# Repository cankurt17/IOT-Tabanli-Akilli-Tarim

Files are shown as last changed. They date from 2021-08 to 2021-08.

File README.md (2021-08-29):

# IOT-Tabanli-Akilli-Tarim

- Bu proje tarımda sulama ve gübrelemedeki insan yüklerini azaltmak için geliştirilmiştir. Otomatik gübreleme ve 2 farklı sulama modu seçeneği ile maksimum verimde gübreleme ve sulama yapabilmektedir. Kullanıcı dostu arayüzü ve hatasız çalışma sistemi ile çiftçilerin şüphesiz tercih edeceği bir proje olması hedeflenmektedir. 
- Sistemin çalışma mantığı kullanıcı panodan veya mobil uygulamadan sulama yapacağı saat aralığını sisteme girer. Örneğin pazartesi saat 20.00 - 21.30 aralığında sisteme sulama girilmiş ise sistem belirtilen saat aralığında bahçenin suyunu açar ve kullanıcıya bilgilendirme maili gönderir. Eğer kullanıcı gübre miktarını girerek gübreleme yapılacağını sisteme belirtmiş ise sistem suyun debisini hesaplayarak girilen  miktardaki gübreyi suya aktarır ve gübrelemeyi tamamlar.
  Bütün bu sistemin çalışması sırasında bir arıza olursa kullanıcı mail ile bilgilendirilir. Örneğin su kesintisi,gübrenin bitmesi, elektrik kesintisi vb. Sulama sırasında sorun yaşanmaz ise kullanıcı bilgilendirilerek sulama kaydı tutulur ve tabloya aktarılır.
- Otomatik modda kullanıcının girdiği nem değerleri baz alınarak sistem   saatten bağımsız olarak toprağı istenilen nem aralığında tutar.Manuel modda ise kullanıcının girdiği saat aralıklarında sulama yapmaktadır. 

# Proje Özellikleri

- Otomatik ve manuel olmak üzere 2 farklı modda sulama seçeneği
- Mobil uygulama destekli
- Kullanıcı dostu kontrol panosu
- Otomatik sulama 
- Otomatik gübreleme 
- Bahçe toprağının anlık nem takibi
- Havanın sıcaklık ve nem takibi
- Gübrenin miktarı takibi
- Suyun durum ve debi takibi
- Bildirim ve mail ile bilgilendirme servisi
- Su sayacı 
- Ayrıntılı sulama kayıt tablosu
- Arıza rapor servisi 

# Prototip Görselleri
prototip1
prototoip2

# Mobil uygulama görselleri

uygulama1
uygulama2
uygulama3
uygulama4
uygulama5
uygulama6

# Pano görselleri

pano1
pano2
pano3
pano4

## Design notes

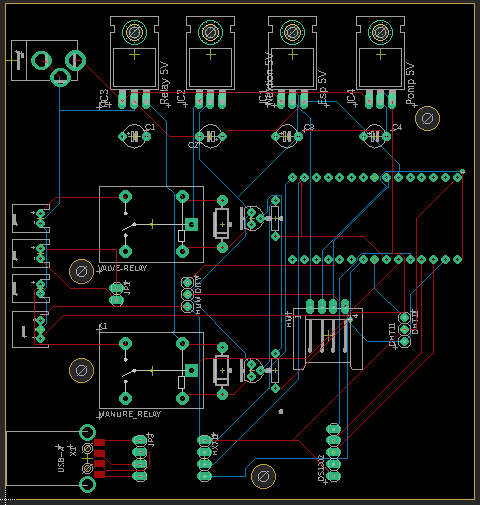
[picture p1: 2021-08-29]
Eagle/board.png

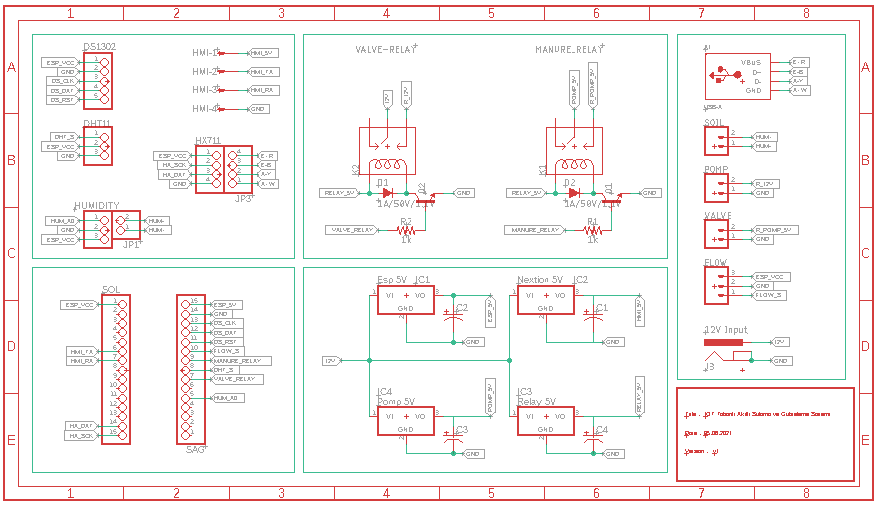
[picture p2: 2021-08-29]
Eagle/schema.png

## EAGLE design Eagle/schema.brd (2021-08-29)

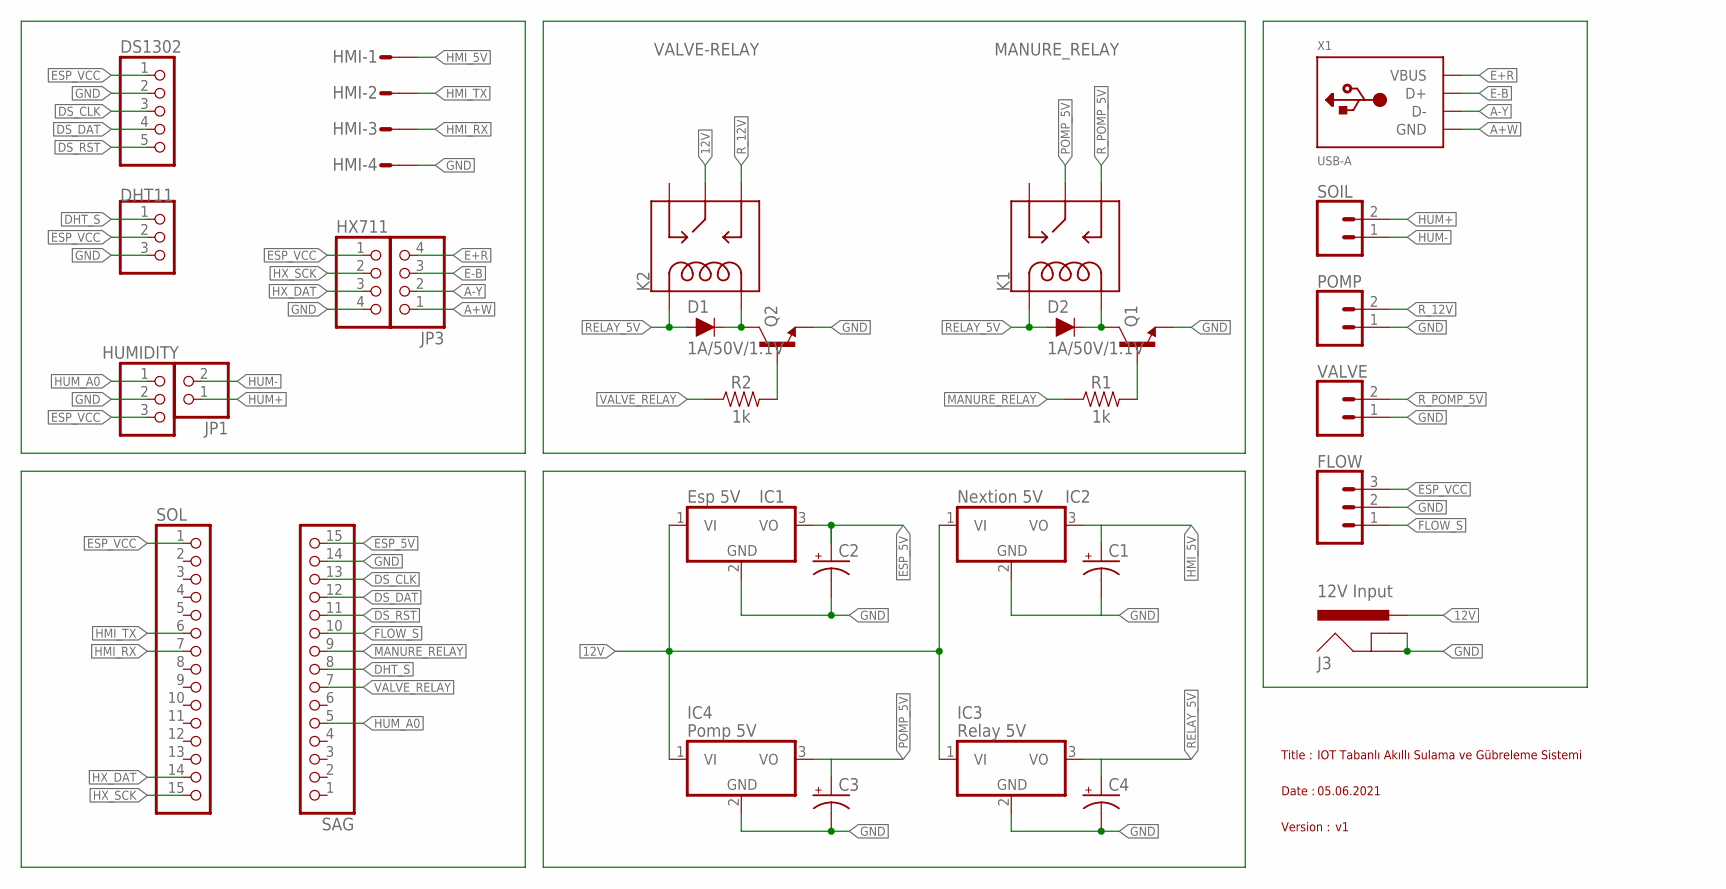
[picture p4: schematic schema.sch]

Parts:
C1, C2, C3, C4: CPOL-USE5-5; E5-5
D1, D2: 1A/50V/1.1V; DIODE-1N4001
DHT11: DHT11; 1X03
DS1302: PINHD-1X5; 1X05
FLOW: CONN_03JST-PTH; JST-3-PTH
HMI: L04P
HUMIDITY: PINHD-1X3; 1X03
HX711: PINHD-1X4; 1X04
IC1: Esp 5V; TO220H
IC2: Nextion 5V; TO220H
IC3: Relay 5V; TO220H
IC4: Pomp 5V; TO220H
J3: 12V Input; POWER_JACK_PTH_LOCK
JP1: PINHD-1X2; 1X02
JP3: PINHD-1X4; 1X04
K1: MANURE_RELAY; RELAY_G5LE
K2: VALVE-RELAY; RELAY_G5LE
POMP: CONN_02-JST-2-PTH-NO_SILK; JST-2-PTH-NS
Q1, Q2: 200mA/40V; TO-92
R1, R2: 1k; AXIAL-0.3
SAG: PINHD-1X15-CB; 1X15-CB
SOIL: CONN_02-JST-2-PTH-NO_SILK; JST-2-PTH-NS
SOL: PINHD-1X15-CB; 1X15-CB
VALVE: CONN_02-JST-2-PTH-NO_SILK; JST-2-PTH-NS
X1: USB-A; MOLEX_480371000

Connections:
12V: IC1.1 (VI), IC2.1 (VI), IC3.1 (VI), IC4.1 (VI), J3.PWR, K2.1 (MAIN)
A+W: JP3.1, X1.4 (GND)
A-Y: JP3.2, X1.2 (D-)
DHT_S: DHT11.1, SAG.8
DS_CLK: DS1302.3, SAG.13
DS_DAT: DS1302.4, SAG.12
DS_RST: DS1302.5, SAG.11
E+R: JP3.4, X1.1 (VBUS)
E-B: JP3.3, X1.3 (D+)
ESP_5V: C2.+, IC1.3 (VO), SAG.15
ESP_5V1: C1.+
ESP_5V2: C4.+
ESP_5V3: C3.+
ESP_VCC: DHT11.2, DS1302.1, FLOW.3, HUMIDITY.3, HX711.1, SOL.1
FLOW_S: FLOW.1, SAG.10
GND: C2.-, C3.-, C4.-, DHT11.3, DS1302.2, FLOW.2, HMI.4, HUMIDITY.2, HX711.4, IC1.2 (GND), IC2.2 (GND), IC3.2 (GND), IC4.2 (GND), J3.GND, J3.GNDBREAK, POMP.1, Q1.1 (E), Q2.1 (E), SAG.14, VALVE.1
GND2: C1.-
HMI_5V: HMI.1, IC2.3 (VO)
HMI_RX: HMI.3, SOL.7
HMI_TX: HMI.2, SOL.6
HUM+: JP1.1, SOIL.2
HUM-: JP1.2, SOIL.1
HUM_A0: HUMIDITY.1, SAG.5
HX_DAT: HX711.3, SOL.14
HX_SCK: HX711.2, SOL.15
MANURE_RELAY: R1.P$1 (1), SAG.9
unnamed: D2.C, K1.5 (COIL2), Q1.3 (C)
unnamed: Q1.2 (B), R1.P$2 (2)
unnamed: D1.C, K2.5 (COIL2), Q2.3 (C)
unnamed: Q2.2 (B), R2.P$2 (2)
POMP_5V: IC4.3 (VO), K1.1 (MAIN)
RELAY_5V: D1.A, D2.A, IC3.3 (VO), K1.2 (COIL1), K2.2 (COIL1)
R_12V: K2.3 (NO), POMP.2
R_POMP_5V: K1.3 (NO), VALVE.2
VALVE_RELAY: R2.P$1 (1), SAG.7

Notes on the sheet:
Title :
IOT Tabanlı Akıllı Sulama ve Gübreleme Sistemi
Date :
05.06.2021
Version :

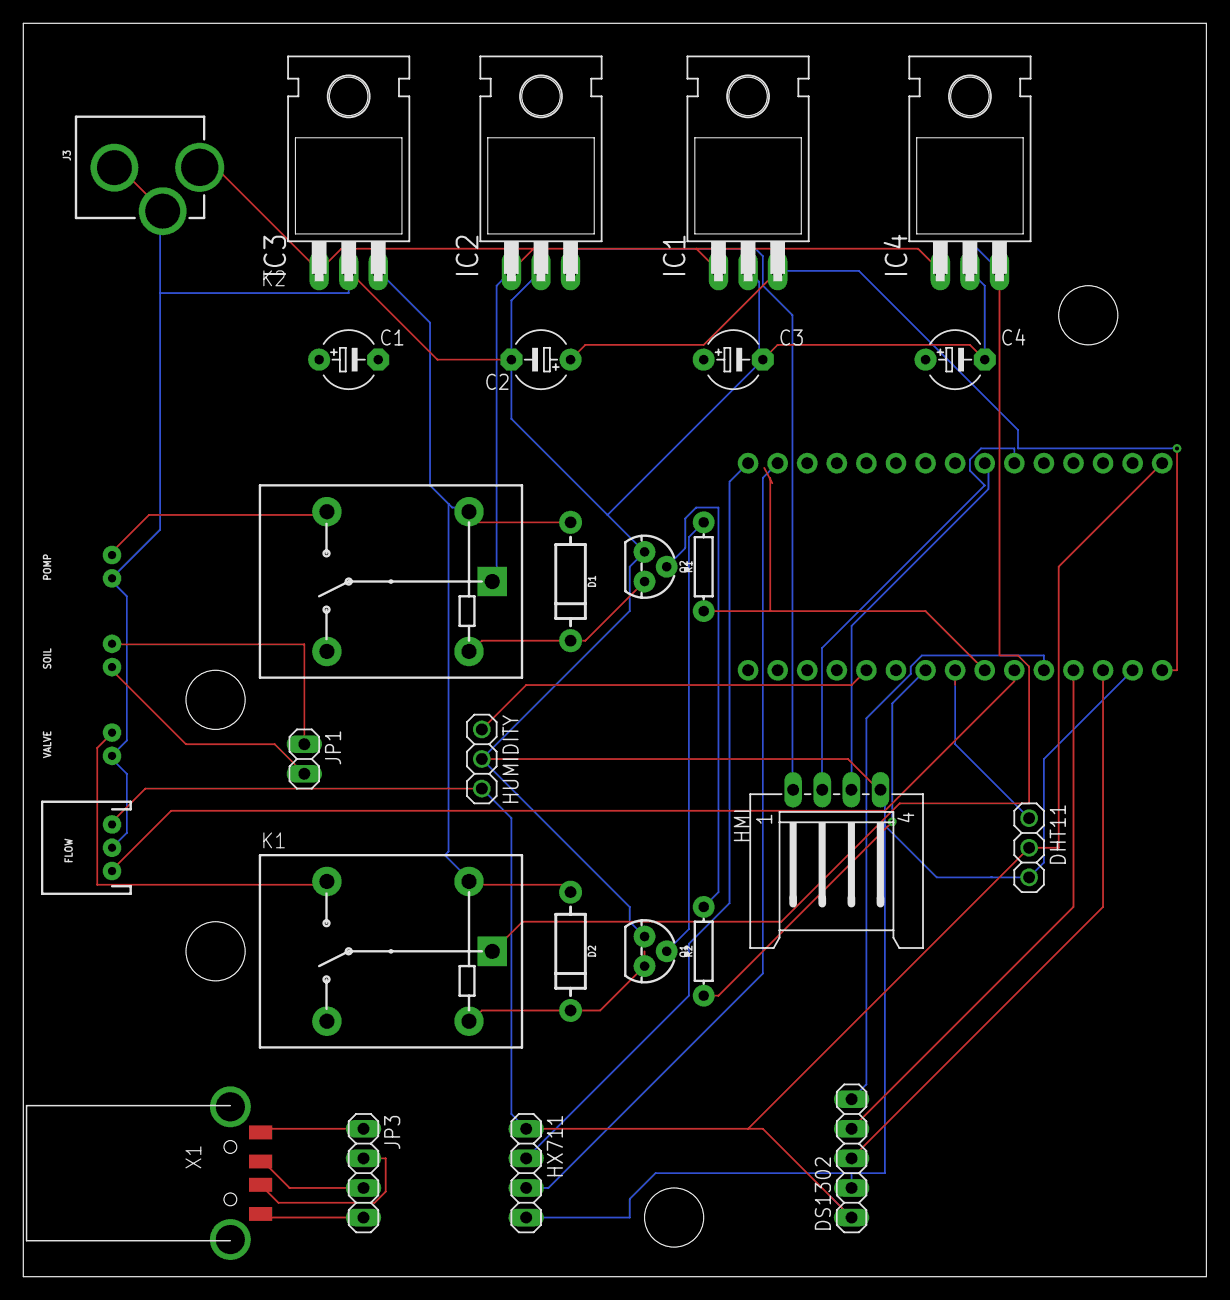
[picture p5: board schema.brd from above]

Board: 2 copper layers, 101.6 x 107.6 mm, 31 parts (0 on the bottom side), 31 nets.

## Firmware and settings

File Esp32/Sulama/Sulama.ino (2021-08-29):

#include "EasyNextionLibrary.h"
#include <EEPROM.h>
#include <virtuabotixRTC.h>
#include <DHT.h>
#include <WiFi.h>
#include <HTTPClient.h>
#include <Arduino_JSON.h>
#include "HX711.h"


EasyNex myNex(Serial2);
#define DHTTYPE DHT11

String id_sulama_durum[7] = {"manuel_ekran.cPt", "manuel_ekran.cSl", "manuel_ekran.cCrs", "manuel_ekran.cPrs", "manuel_ekran.cCm", "manuel_ekran.cCt", "manuel_ekran.cPz",};
String id_sulama_baslaSaat[7] = {"manuel_ekran.ptBasla", "manuel_ekran.slBasla", "manuel_ekran.crsBasla", "manuel_ekran.prsBasla", "manuel_ekran.cmBasla", "manuel_ekran.ctBasla", "manuel_ekran.pzBasla",};
String id_sulama_bitisSaat[7] = {"manuel_ekran.ptBitir", "manuel_ekran.slBitir", "manuel_ekran.crsBitir", "manuel_ekran.prsBitir", "manuel_ekran.cmBitir", "manuel_ekran.ctBitir", "manuel_ekran.pzBitir",};

String id_gubre_durum[7] = {"gubre_ayar.g_cPt", "gubre_ayar.g_cSl", "gubre_ayar.g_cCrs", "gubre_ayar.g_cPrs", "gubre_ayar.g_cCm", "gubre_ayar.g_cCt", "gubre_ayar.g_cPz",};
String id_gubre_miktar[7] = {"gubre_ayar.ptMiktar", "gubre_ayar.slMiktar", "gubre_ayar.crsMiktar", "gubre_ayar.prsMiktar", "gubre_ayar.cmMiktar", "gubre_ayar.ctMiktar", "gubre_ayar.pzMiktar",};
String id_gubre_birim[7] = {"gubre_ayar.ptBirim", "gubre_ayar.slBirim", "gubre_ayar.crsBirim", "gubre_ayar.prsBirim", "gubre_ayar.cmBirim", "gubre_ayar.ctBirim", "gubre_ayar.pzBirim",};

String id_sulama_nem[2] = {"manuel_nem.nemBasla", "manuel_nem.nemBitir"};
String id_sulama_mod = {"mod_ekran.mod" };
String id_dekar = {"dekar_ekran.dekar" };
String id_suSayaci = {"su_sayaci.suSayaci" };

String gunler[7] = {"Pazartesi", "Salı", "Çarşamba", "Perşembe", "Cuma", "Cumartesi", "Pazar"};

const char* mailServer = "http://maker.ifttt.com/trigger/esp_mail/with/key/dOcBsvl9Rl1Jaqve76vQB2";

const char* writeServer = "https://enlodi.com/Sulama-Proje/post-esp-data.php";
const char* readServer = "https://enlodi.com/Sulama-Proje/";
String apiKeyValue = "tPmAT5Ab3j7F9";
String httpRequestData;
//const char* ssid     = "KURT";
//const char* password = "enlodi.46";
const char* ssid     = "G4_7465";
const char* password = "11111111";

String mailAdresi;

unsigned long eskizaman = 0;
int sulama_durum[7];
String sulama_baslaSaat[7];
String sulama_bitisSaat[7];
int gubre_durum[7];
int gubre_miktar[7];
String gubre_birim[7];
int sulama_nem[2];
int sulama_mod;
int dekar;
int suSayaci;
int toplamSulama;
bool suKesintisi = false;
int kesintiSayisi = 0;
unsigned long kesintiZaman = 0;
String gubreBirimler[2] = {"mL", "L"};

uint32_t ekranKayit = 0 ;
String text = "";
uint32_t asd = 0 ;

byte lsb;
byte msb;
unsigned long ekran_zaman = 0;
String suDurum = "KAPALI";
String gubreDurum = "KAPALI";

///////////////////////////////// Pinler
int suVana = 33;
int gubreVana = 26;
int Saat_CLK_PIN = 13 ;
int Saat_DT_PIN = 12;
int Saat_RST_PIN = 14 ;
const int DHTPin = 25;
int nem_sensor = 35;
const int debi_sensor = 27;
#define DOUT 22
#define CLK 23


HX711 scale(DOUT, CLK);
float kalibrasyon_faktoru = 103000;

bool debiKontrol;
int hata = 1;

int debi = 0;
int nemdeger = 0;
String sulamaRapor;
int ortDebi = 0;
int _gun;

int debiSaniye = 120000;
int gubreSaniye = 300000;
int veriMod;
int veriGubre;
String veriBaslamaSaati;
String veriBitisSaati;
int veriBaslamaNem;
int veriBitisNem;
int veriAnlikNem;
unsigned long veriSuBaslama = 0;
unsigned long mysql_zaman = 0;
float veriAtilacakGubre = 0;
float veriAnlikGubre = 0;
float gubreMiktar = 0;

volatile int  Pulse_Count;
unsigned int  Liter_per_hour;
unsigned long Current_Time, Loop_Time;

DHT dht(DHTPin, DHTTYPE);
virtuabotixRTC myRTC(Saat_CLK_PIN, Saat_DT_PIN, Saat_RST_PIN);

void setup() {
  myNex.begin(115200); // Begin the object with a baud rate of 9600
  Serial.begin(115200);                  // If no parameter was given in the begin(), the default baud rate of 9600 will be used v
  EEPROM.begin(512);
  dht.begin();
  pinMode(nem_sensor, INPUT);
  pinMode(suVana, OUTPUT);
  pinMode(gubreVana, OUTPUT);
  pinMode(debi_sensor, INPUT);
  digitalWrite(suVana, LOW);
  scale.set_scale(kalibrasyon_faktoru); // Ölçek ayarlandı
  scale.tare(); // Ölçek sıfırlandı
  attachInterrupt(digitalPinToInterrupt(debi_sensor), Detect_Rising_Edge, RISING);
  Current_Time = millis();
  Loop_Time = Current_Time;
  loadEEPROM();
  loadNextion();
  initWiFi();
}


void loop() {
  myNex.NextionListen();
  myRTC.updateTime();
  homePage();
  ekranKayit = myNex.readNumber ( "settings.kayitEkran.val" );
  Current_Time = millis();
  getDebiSensor();
  sulamaKontrol();
  mysqlKontrol();
  debiHesapla();
  suKontrol();
  wifiKontrol();
  if (ekranKayit == 1) {

    getNextionMod();
    writeModEEPROM();
    mysqlModKayit();
  }
  if (ekranKayit == 2) {
    getNextionSulama();
    writeSulamaEEPROM();
    mysqlGunKayit();
  }
  if (ekranKayit == 3) {
    getNextionNem();
    writeNemEEPROM();
    mysqlNemKayit();
  }
  if (ekranKayit == 4) {
    getNextionGubre();
    writeGubreEEPROM();
    mysqlGubreKayit();
  }
  if (ekranKayit == 5) {
    getNextionDekar();
    writeDekarEEPROM();
    kayitEkran();
  }
  if (ekranKayit == 6) {
    writeSayacEEPROM(0);
    kayitEkran();
  }
  if (ekranKayit == 7) {
    saatKayit();
    kayitEkran();
  }
}

//////////////////////////////////////////////////////////////////////////////////////////////////////  getNextion
void getNextionSulama() {
  for (int i = 0; i <= 6; i++) {
    sulama_durum[i] = myNex.readNumber( id_sulama_durum[i] + ".val" );
    sulama_baslaSaat[i] = myNex.readStr( id_sulama_baslaSaat[i] + ".txt" );
    sulama_bitisSaat[i] = myNex.readStr( id_sulama_bitisSaat[i] + ".txt" );
  }
  for (int i = 0; i <= 6; i++) {
    Serial.println(sulama_durum[i]);
    Serial.println(sulama_baslaSaat[i]);
    Serial.println(sulama_bitisSaat[i]);
  }
}
void getNextionNem() {
  sulama_nem[0] = myNex.readNumber( id_sulama_nem[0] + ".val"  );
  sulama_nem[1] = myNex.readNumber( id_sulama_nem[1] + ".val"  );
}
void getNextionMod() {
  sulama_mod = myNex.readNumber( id_sulama_mod + ".val"  );
  String abc = myNex.readStr( "mod_ekran.b2.txt" );
  Serial.println(sulama_mod);
  Serial.println(abc);
}
void getNextionGubre() {
  for (int i = 0; i <= 6; i++) {
    gubre_durum[i] = myNex.readNumber( id_gubre_durum[i] + ".val" );
    gubre_miktar[i] = myNex.readStr( id_gubre_miktar[i] + ".txt" ).toInt();
    gubre_birim[i] = myNex.readStr( id_gubre_birim[i] + ".txt" );
  }
  for (int i = 0; i <= 6; i++) {
    Serial.println(gubre_durum[i]);
    Serial.println(gubre_miktar[i]);
    Serial.println(gubre_birim[i]);
  }
}

void getNextionDekar() {
  dekar = myNex.readNumber( id_dekar + ".val"  );
}
//////////////////////////////////////////////////////////////////////////////////////////////////////  setNextion
void setNextionSulama() {
  for (int i = 0; i <= 6; i++) {
    myNex.writeNum( id_sulama_durum[i] + ".val", sulama_durum[i] );
    myNex.writeStr( id_sulama_baslaSaat[i] + ".txt", sulama_baslaSaat[i] );
    myNex.writeStr( id_sulama_bitisSaat[i] + ".txt", sulama_bitisSaat[i]);
  }
}
void setNextionNem() {
  myNex.writeNum( id_sulama_nem[0] + ".val", sulama_nem[0]);
  myNex.writeNum( id_sulama_nem[1] + ".val", sulama_nem[1]);
}
void setNextionMod() {
  myNex.writeNum( id_sulama_mod + ".val", sulama_mod);
}
void setNextionGubre() {
  for (int i = 0; i <= 6; i++) {
    myNex.writeNum( id_gubre_durum[i] + ".val" , gubre_durum[i]);
    myNex.writeStr( id_gubre_miktar[i] + ".txt", String(gubre_miktar[i]) );
    myNex.writeStr( id_gubre_birim[i] + ".txt" , gubre_birim[i]);
  }
}
void setNextionDekar() {
  myNex.writeNum( id_dekar + ".val", dekar);
}
void setNextionSayac() {
  myNex.writeNum( id_suSayaci + ".val", suSayaci);
}
//////////////////////////////////////////////////////////////////////////////////////////////////////  writeEEPROM
void writeSulamaEEPROM() {
  int addr = 1;
  for (int i = 0; i <= 6; i++) {
    writeEEPROM(addr, sulama_durum[i]);
    writeEEPROM(addr + 1, sulama_baslaSaat[i].substring(0, 2).toInt());
    writeEEPROM(addr + 2, sulama_baslaSaat[i].substring(3, 5).toInt());
    writeEEPROM(addr + 3, sulama_bitisSaat[i].substring(0, 2).toInt());
    writeEEPROM(addr + 4, sulama_bitisSaat[i].substring(3, 5).toInt());
    addr = addr + 5;
  }

}
void writeNemEEPROM() {
  writeEEPROM(40, sulama_nem[0]);
  writeEEPROM(41, sulama_nem[1]);
}
void writeModEEPROM() {
  writeEEPROM(42, sulama_mod);
}
void writeGubreEEPROM() {
  int addr = 45;
  for (int i = 0; i <= 6; i++) {
    intToByte(gubre_miktar[i]);
    writeEEPROM(addr, gubre_durum[i]);
    writeEEPROM(addr + 1, lsb);
    writeEEPROM(addr + 2, msb);
    writeEEPROM(addr + 3, getGubreBirim(gubre_birim[i]));
    addr = addr + 4;
  }
}
void writeDekarEEPROM() {
  intToByte(dekar);
  writeEEPROM(90, lsb);
  writeEEPROM(91, msb);
}
void writeSayacEEPROM(int sayac) {
  intToByte(sayac);
  writeEEPROM(92, lsb);
  writeEEPROM(93, msb);
}
//////////////////////////////////////////////////////////////////////////////////////////////////////  readEEPROM
void readSulamaEEPROM() {
  EEPROM.begin(512);
  int addr = 1;
  for (int i = 0; i <= 6; i++) {
    sulama_durum[i] = EEPROM.read(addr);
    sulama_baslaSaat[i] = setClockText(EEPROM.read(addr + 1), EEPROM.read(addr + 2));
    sulama_bitisSaat[i] = setClockText(EEPROM.read(addr + 3), EEPROM.read(addr + 4));
    addr = addr + 5;
  }
}

void readNemEEPROM() {
  sulama_nem[0] = EEPROM.read(40);
  sulama_nem[1] = EEPROM.read(41);
}
void readModEEPROM() {
  EEPROM.begin(512);
  sulama_mod = EEPROM.read(42);
}

void readGubreEEPROM() {
  int addr = 45;
  for (int i = 0; i <= 6; i++) {
    gubre_durum[i] =  EEPROM.read(addr);
    gubre_miktar[i] =  byteToInt(EEPROM.read(addr + 1), EEPROM.read(addr + 2));
    gubre_birim[i] =  gubreBirimler[EEPROM.read(addr + 3)] ;
    addr = addr + 4;
  }
}

void readDekarEEPROM() {
  EEPROM.begin(512);
  dekar = byteToInt(EEPROM.read(90), EEPROM.read(91));
}

void readSayacEEPROM() {
  EEPROM.begin(512);
  suSayaci = byteToInt(EEPROM.read(92), EEPROM.read(93));
}
//////////////////////////////////////////////////////////////////////////////////////////////////////  startApp

void loadEEPROM() {
  readSulamaEEPROM();
  readNemEEPROM();
  readModEEPROM();
  readGubreEEPROM();
  readDekarEEPROM();
  readSayacEEPROM();
}
void loadNextion() {
  setNextionSulama();
  setNextionNem();
  setNextionMod();
  setNextionGubre();
  setNextionDekar();
  setNextionSayac();
}
/////////////////////////////////////////////////////////////////////////////////////////////////////


void writeEEPROM(int addr, int value) {
  if (EEPROM.read(addr) != value) {
    EEPROM.begin(512);
    EEPROM.write(addr, value);
    EEPROM.commit();
  }
}

void intToByte(int value) {
  lsb = lowByte(value);
  msb = highByte(value);
}

int byteToInt(byte a, byte b) {
  return a + (b << 8);
}

int getGubreBirim(String birim) {
  int _birim;
  if (birim == "mL") {
    _birim = 0;
  } else if (birim == "L") {
    _birim = 1;
  }
  return _birim;
}

String setClockText(int saat, int dk) {
  String deger;
  if (saat < 10) {
    if (dk < 10) {
      deger = "0" + String(saat) + ":" + "0" + String(dk);
    } else {
      deger = "0" + String(saat) + ":" + String(dk);
    }
  } else if (dk < 10) {
    deger = String(saat) + ":" + "0" + String(dk);
  } else {
    deger = String(saat) + ":" + String(dk);
  }
  return deger;
}

void kayitEkran() {
  myNex.writeNum( "p1.pic", 23 );
  myNex.writeStr ("t2.txt", "Bağlantı başarılı.");
  myNex.writeStr( "vis p1,1");
  myNex.writeStr( "vis t2,1");
  delay(100);
  myNex.writeNum( "t0.pco", 1024 );
  myNex.writeStr ("t0.txt", "Kaydedildi.");
  delay(500);
  myNex.writeNum( "settings.kayitEkran.val", 0 );
  myNex.writeStr ("page settings");
  delay(100);
}


void homePage() {
  if (millis() - ekran_zaman > 2000) {
    nemdeger = analogRead(nem_sensor);
    nemdeger = map(nemdeger, 0, 4095, 100, 0);
    gubreMiktar = getTarti();
    if (digitalRead(suVana) == HIGH) {
      suDurum = "AÇIK";
    } else {
      suDurum = "KAPALI";
    }
    if (digitalRead(gubreVana) == HIGH) {
      gubreDurum = "AÇIK";
    } else {
      gubreDurum = "KAPALI";
    }
    myNex.writeNum( "home.saat.val", myRTC.hours);
    myNex.writeNum( "home.dk.val", myRTC.minutes);
    myNex.writeStr( "home.day.txt", gunler[myRTC.dayofweek - 1]);
    myNex.writeStr( "home.sic.txt", String((int)dht.readTemperature()) + "°C");
    myNex.writeStr( "home.nem.txt", "%" + String((int)dht.readHumidity()));
    myNex.writeStr( "home.tnem.txt", "%" + String(nemdeger));
    myNex.writeStr( "home.debi.txt", String(debi) + " L/sa");
    myNex.writeStr( "home.rapor.txt", suRapor());
    myNex.writeStr( "home.suDurum.txt", suDurum);
    myNex.writeStr( "home.gMiktar.txt", String(gubreMiktar, 1) + " Litre");
    myNex.writeStr( "home.gubreDurum.txt", gubreDurum);
    loadNextion();
    ekran_zaman = millis();
  }
}

void saatKayit() {
  int gun = getDay(myNex.readStr("saat_ayar.t0.txt" ));
  int saat = myNex.readNumber("saat_ayar.n0.val" );
  int dk = myNex.readNumber("saat_ayar.n1.val" );
  myRTC.setDS1302Time(00, dk, saat, gun, 10, 1, 2020);
}

int getDay(String gun) {
  int _gun;
  if (gun == "Pazartesi") {
    _gun = 1;
  } else if (gun == "Salı") {
    _gun = 2;
  } else if (gun == "Çarşamba") {
    _gun = 3;
  } else if (gun == "Perşembe") {
    _gun = 4;
  } else if (gun == "Cuma") {
    _gun = 5;
  } else if (gun == "Cumartesi") {
    _gun = 6;
  } else if (gun == "Pazar") {
    _gun = 7;
  }
  return _gun;
}


void getDebiSensor() {
  Current_Time = millis();
  if (Current_Time >= (Loop_Time + 1000))
  {
    Loop_Time = Current_Time;
    Liter_per_hour = (Pulse_Count * 60 / 7.5);
    Pulse_Count = 0;
    debi = Liter_per_hour;
  }
}


void Detect_Rising_Edge ()
{
  Pulse_Count++;
}

String suRapor() {
  int _gun = myRTC.dayofweek - 1;
  if (digitalRead(suVana) == LOW) {

    int saat = myRTC.hours * 100 + myRTC.minutes;
    int basla  = vanaSaatKontrol(sulama_baslaSaat[_gun]);
    if (sulama_durum[_gun] == 1 && saat <= basla) {
      if (gubre_durum[_gun] == 1) {
        return sulamaRapor = "Sıradaki sulama " + gunler[_gun] + " " + sulama_baslaSaat[_gun] + " / " + sulama_bitisSaat[_gun] + "  Gübreleme VAR";
      } else {
        return sulamaRapor = "Sıradaki sulama " + gunler[_gun] + " " + sulama_baslaSaat[_gun] + " / " + sulama_bitisSaat[_gun] + "  Gübreleme YOK";
      }
    }
    for (int i = _gun + 1; i <= 6; i++) {
      int saat = myRTC.hours * 100 + myRTC.minutes;
      int basla  = vanaSaatKontrol(sulama_baslaSaat[i]);

      if (sulama_durum[i] == 1) {
        if (gubre_durum[i] == 1) {
          return sulamaRapor = "Sıradaki sulama " + gunler[i] + " " + sulama_baslaSaat[i] + " / " + sulama_bitisSaat[i] + "  Gübreleme VAR";
        } else {
          return sulamaRapor = "Sıradaki sulama " + gunler[i] + " " + sulama_baslaSaat[i] + " / " + sulama_bitisSaat[i] + "  Gübreleme YOK";
        }
      }

    }
    for (int i = 0; i <= 6; i++) {
      int saat = myRTC.hours * 100 + myRTC.minutes;
      int basla  = vanaSaatKontrol(sulama_baslaSaat[i]);

      if (sulama_durum[i] == 1) {
        if (gubre_durum[i] == 1) {
          return sulamaRapor = "Sıradaki sulama " + gunler[i] + " " + sulama_baslaSaat[i] + " / " + sulama_bitisSaat[i] + "  Gübreleme VAR";
        } else {
          return sulamaRapor = "Sıradaki sulama " + gunler[i] + " " + sulama_baslaSaat[i] + " / " + sulama_bitisSaat[i] + "  Gübreleme YOK";
        }
      }
    }
    return sulamaRapor = "Kayıtlı sulama yok";
  } else {
    if (gubre_durum[_gun] == 1) {
      return sulamaRapor = "Bahçe şuanda sulanıyor Gübreleme VAR";
    } else {
      return sulamaRapor = "Bahçe şuanda sulanıyor Gübreleme YOK";
    }
  }
}
void sulamaKontrol() {
  if (sulama_mod == 1) {
    manSulama();
  }
  else if (sulama_mod == 0) {
    otoSulama();
  }
}
void manSulama() {
  int _gun = myRTC.dayofweek - 1;
  if (sulama_durum[_gun] == 1 ) {
    int basla  = vanaSaatKontrol(sulama_baslaSaat[_gun]);
    int bitir  = vanaSaatKontrol(sulama_bitisSaat[_gun]);
    int saat = myRTC.hours * 100 + myRTC.minutes;
    if (basla <= saat && saat <= bitir) {
      if (digitalRead(suVana) == LOW) {
        digitalWrite(suVana, HIGH);
        Serial.println("1");
        suDurum = "AÇIK";
        debiKontrol = true;
        ortDebi = 0;
        suKesintisi = false;
        veriSuBaslama = millis();
        manSulamaMail();
        sulamaKayitVerileri();
      } else {
        gubreKontrol();
      }
    } else if (digitalRead(suVana) == HIGH) {
      digitalWrite(suVana, LOW);
      Serial.println("2");
      suDurum = "KAPALI";
      sulamaBittiMail();
      sulamaBitis();
    }
  } else {
    if (digitalRead(suVana) == HIGH) {
      digitalWrite(suVana, LOW);
      Serial.println("3");
      suDurum = "KAPALI";
    }
  }
}

void otoSulama() {
  if (nemdeger <= sulama_nem[0] ) {
    if (digitalRead(suVana) == LOW) {
      digitalWrite(suVana, HIGH);
      Serial.println("4");
      suDurum = "AÇIK";
      ortDebi = 0;
      suKesintisi = false;
      veriSuBaslama = millis();
      debiKontrol = true;
      otoSulamaMail();
      sulamaKayitVerileri();
    }
  } else if (sulama_nem[1] < nemdeger) {
    if (digitalRead(suVana) == HIGH) {
      digitalWrite(suVana, LOW);
      Serial.println("5");
      suDurum = "KAPALI";
      sulamaBitis();
      sulamaBittiMail();
    }
  }
}


void sulamaVerileri() {
  _gun = myRTC.dayofweek - 1;
  nemdeger = analogRead(nem_sensor);
  nemdeger = map(nemdeger, 0, 4095, 100, 0);
  gubreMiktar = getTarti();
  veriMod = sulama_mod;
  veriGubre = gubre_durum[myRTC.dayofweek - 1];
  veriBaslamaSaati = sulama_baslaSaat[_gun];
  veriBitisSaati = sulama_bitisSaat[_gun];
  veriAnlikNem = nemdeger;
  veriSuBaslama = millis();
  veriAnlikGubre = gubreMiktar;
}

int _nemdegerKayit;
int _modKayit;
int _baslangisSaati;
int _baslangisDk;
void sulamaKayitVerileri() {
  _gun = myRTC.dayofweek - 1;
  _nemdegerKayit = analogRead(nem_sensor);
  _nemdegerKayit = map(_nemdegerKayit, 0, 4095, 100, 0);
  _modKayit = sulama_mod;
  veriGubre = gubre_durum[myRTC.dayofweek - 1];
  _baslangisSaati = myRTC.hours;
  _baslangisDk = myRTC.minutes;
}

void sulamaBitis() {
  ortDebi = 0;
  String _mod;
  String baslangic = String(_baslangisSaati) + ":" + String(_baslangisDk);
  String bitis = String(myRTC.hours) + ":" + String(myRTC.minutes);
  int _toplamSulama = toplamDk(baslangic, bitis);
  nemdeger = analogRead(nem_sensor);
  nemdeger = map(nemdeger, 0, 4095, 100, 0);
  if (_modKayit == 1) {
    _mod = "Manuel";
  } else {
    _mod = "Otomatik";
    veriGubre = 0;
  }
  readSayacEEPROM();
  suSayaci = suSayaci + _toplamSulama;
  Serial.print(suSayaci);
  writeSayacEEPROM(suSayaci);
  loadEEPROM();
  loadNextion();
  httpRequestData = "api_key=" + apiKeyValue + "&day=" +  gunler[myRTC.dayofweek - 1] +
                    "&start=" + baslangic + "&stop=" + bitis +
                    "&toplam=" + _toplamSulama  + "&startnem=" + _nemdegerKayit +
                    "&stopnem=" + nemdeger + "&durum=" + _mod + "&ortamnem=" + veriGubre + "&ortamsicaklik=" + hata + "&tablo=" + "sulama_kayit";
  loadMysql(httpRequestData);
  hata = 1;
}

void gubreKontrol() {
  _gun = myRTC.dayofweek - 1;

  int gbr_basla  = vanaSaatKontrol(sulama_baslaSaat[_gun]) + 5;
  int saat = myRTC.hours * 100 + myRTC.minutes;
  if (gubre_durum[_gun] == 1) {
    if (saat >= gbr_basla && digitalRead(gubreVana) == LOW) {
      int birim = getGubreBirim(gubre_birim[_gun]);
      if (birim == 0) {
        gubre_ml_L();
      } else if (birim == 1) {
        gubre_kg_L();
      }
      digitalWrite(gubreVana, HIGH);
      gubreDurum = "AÇIK";
      veriAnlikGubre = gubreMiktar;
      gubreMail();
    } else if (digitalRead(gubreVana) == HIGH) {

      if (suKesintisi == true) {
        digitalWrite(gubreVana, LOW);
        gubre_durum[_gun] = 0;
        gubreDurum = "KAPALI";
        writeGubreEEPROM();
        setNextionGubre();
        hata = 2;
        hataMail(1);
      } else if (gubreMiktar < 0.5) {
        digitalWrite(gubreVana, LOW);
        gubre_durum[_gun] = 0;
        gubreDurum = "KAPALI";
        writeGubreEEPROM();
        setNextionGubre();
        hata = 4;
        hataMail(2);
      }
      else if (veriAnlikGubre - gubreMiktar > veriAtilacakGubre) {
      
        digitalWrite(gubreVana, LOW);
        gubre_durum[_gun] = 0;
        gubreTamamMail();
        gubreDurum = "KAPALI";
        writeGubreEEPROM();
        setNextionGubre();
      }
    }
  }
}

int  vanaSaatKontrol(String saat) {
  return saat.substring(0, 2).toInt() * 100 + saat.substring(3, 5).toInt();
}
int toplamDk(String baslaSaat, String bitirSaat) {
  return (bitirSaat.substring(0, 2).toInt() - baslaSaat.substring(0, 2).toInt()) * 60 + (bitirSaat.substring(3, 5).toInt() - baslaSaat.substring(3, 5).toInt());
}

void debiHesapla() {
  if (debiKontrol == true && digitalRead(suVana) == HIGH) {

    int _gun = myRTC.dayofweek - 1;
    int debi_basla  = vanaSaatKontrol(sulama_baslaSaat[_gun]) + 2;
    int debi_bitir  = vanaSaatKontrol(sulama_baslaSaat[_gun]) + 4;
    int saat = myRTC.hours * 100 + myRTC.minutes;
    if (digitalRead(suVana) == HIGH && ( saat > debi_basla ) &&  ( debi_bitir >= saat ) ) {
      Serial.println("debi basladı");
      ortDebi = (ortDebi + debi) / 2;
    } else if ((saat > debi_bitir )) {
      debiKontrol = false;
      Serial.println(ortDebi);
      debiMail();
    }
  }
}
void gubre_ml_L() {
  //  toplamSulama = toplamDk(veriBaslamaSaati, veriBitisSaati);
  //  veriAtilacakGubre = ((toplamSulama / 60 * ortDebi) *  gubre_miktar[_gun]) / 1000 ;
  veriAtilacakGubre = gubre_miktar[_gun] / 1000 ;
}
void gubre_kg_L() {
  //  toplamSulama = toplamDk(veriBaslamaSaati, veriBitisSaati);
  //  veriAtilacakGubre = ((toplamSulama / 60 * ortDebi) *  gubre_miktar[_gun]) / 1000 ;
  veriAtilacakGubre = gubre_miktar[_gun]  ;
}
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

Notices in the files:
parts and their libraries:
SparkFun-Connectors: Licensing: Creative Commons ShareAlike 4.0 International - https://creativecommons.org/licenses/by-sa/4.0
